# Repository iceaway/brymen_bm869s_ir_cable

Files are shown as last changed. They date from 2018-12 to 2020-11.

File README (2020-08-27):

NOTE
==============
This repo has been cloned with permission from its original author at 
https://git.e1e0.net/brymen_bm869s_ir_cable.git

The modifications I made were to make it work with an attiny84a MCU which I 
happened to have available. The schematic has been updated to reflect this 
as well.
==============

# Brymen 869s Serial cable

BOM:

  * micro controller ATTiny85
  * One infrared diode.
  * One photodiode.
  * 3 resistors (75R 4k7 2k)
  * One NPN BJT (like the 2N2222A)
  * A usb to serial adapter that can provid 5v.

I built it on a perfboard, so no pcb design is provided.

The 3D desigh fits perfectly and leaves 48 x 11 mm (more or less) of
space for the pcb. An STL file can be found at (in case you don't know
how to use FreeCAD):

https://onna.be/files/brymen_cable_attachemnt_v2.stl

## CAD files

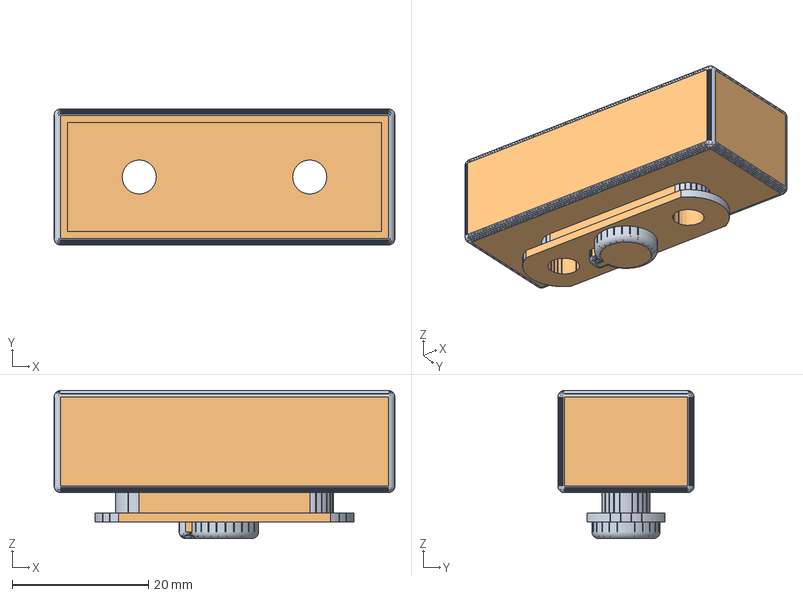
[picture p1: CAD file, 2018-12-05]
CAD/mechanical/cable_attachment.fcstd
50.0 x 20.0 x 21.7 mm
Fillet001 (Meshed)

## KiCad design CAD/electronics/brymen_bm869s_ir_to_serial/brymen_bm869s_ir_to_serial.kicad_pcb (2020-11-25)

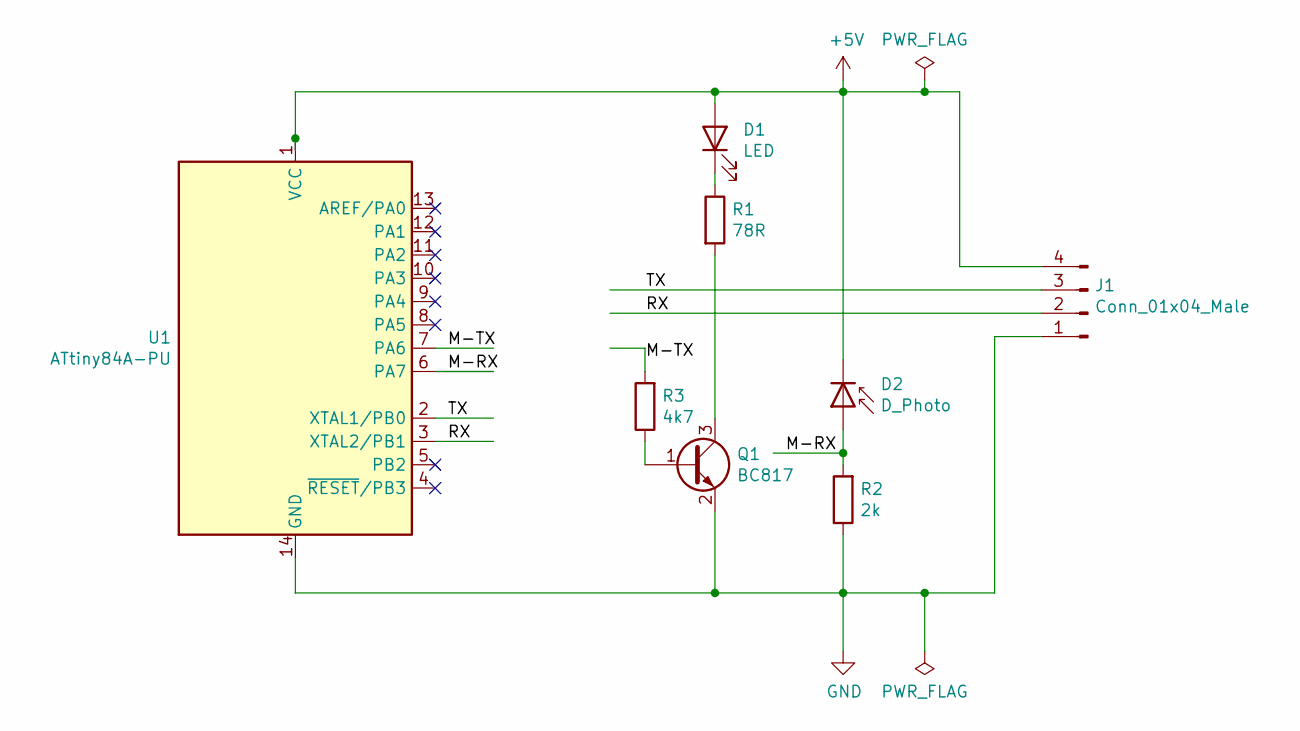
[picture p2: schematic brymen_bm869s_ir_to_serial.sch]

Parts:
D1: LED; LED_D4.0mm
D2: D_Photo; LED_D4.0mm
J1: Conn_01x04_Male; PinHeader_1x04_P2.54mm_Vertical
Q1: BC817; SOT-23
R1: 78R; R_0603_1608Metric
R2: 2k; R_0603_1608Metric
R3: 4k7; R_0603_1608Metric
U1: ATtiny84A-PU; DIP-14_W7.62mm

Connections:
+5V: D1.2 (A), D2.1 (K), J1.4, U1.1 (VCC)
/M-RX: D2.2 (A), R2.2, U1.6 (PA7)
/M-TX: R3.2, U1.7 (PA6)
/RX: J1.2, U1.3 (XTAL2/PB1)
/TX: J1.3, U1.2 (XTAL1/PB0)
GND: J1.1, Q1.2 (E), R2.1, U1.14 (GND)
unnamed: D1.1 (K), R1.1
unnamed: Q1.1 (B), R3.1
unnamed: Q1.3 (C), R1.2

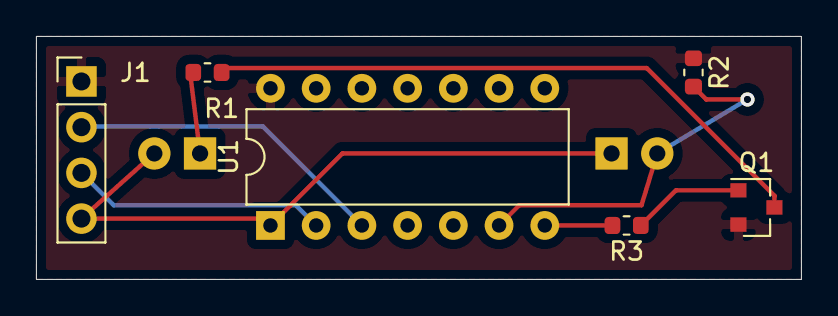
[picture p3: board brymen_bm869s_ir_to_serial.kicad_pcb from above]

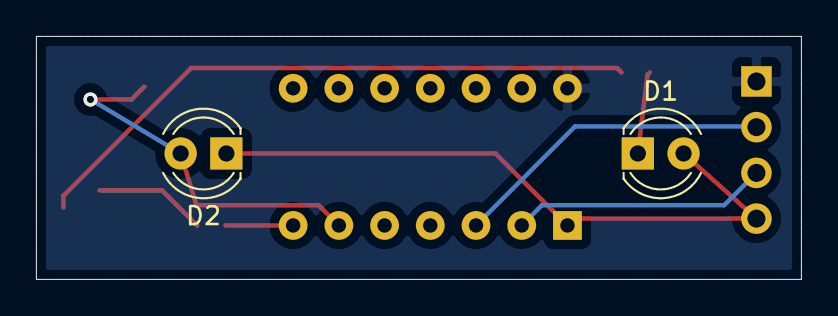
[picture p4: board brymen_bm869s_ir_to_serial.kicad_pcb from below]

Board: 2 copper layers, 42.5 x 13.5 mm, 8 parts (2 on the bottom side), 9 nets.

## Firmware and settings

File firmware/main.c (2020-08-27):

/*
 * all the relevant parts of this code have been shamelessly taken and adapted
 * from here:
 *
 * https://www.eevblog.com/forum/testgear/brymen-ir-connection-protocol-anyone-sniffed-it-yet/msg874805/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
 *
 * All credit goes to eevblog forum user 'jesuscf'. I just adapted to AVR C for
 * the ATTiny85
 */

#include <avr/io.h>
#include <util/delay.h>

#include <bm869s.h>
#include <avr305.h>

#define HIGH 1
#define LOW 0
#define IRTX PA6
#define IRRX PA7

/* Storage for the information received from the multimeter */
#define BM_PBYTES 20 /* 16 bytes with data and 4 bytes with other information */
unsigned char bm[BM_PBYTES];

void digitalWrite(int pin, int state)
{
    if (state == HIGH) {
        PORTA |= (1 << pin);
    } else {
        PORTA &= ~(1 << pin);
    }
}

unsigned char digitalRead(int pin)
{
    return (PINA & (1 << pin));
}

/* Reads a byte from the multimeter */
unsigned char getByte(void)
{
    unsigned char result, mask;

    /* bit by bit check (using shift mask)
     * clock --> check --> "unclock" */
    for (mask = 1, result = 0; mask != 0; mask <<= 1) {
        digitalWrite(IRTX, HIGH);
        _delay_us(250);

        /* checking on low instead of high, so maybe we can reuse
         * some work done on eevblog forum */
        if (digitalRead(IRRX) == LOW) result |= mask;

        digitalWrite(IRTX, LOW);
        _delay_us(250);
    }
    return result;
}

/* Reads 20 bytes from the multimeter */
int readBM689s(void)
{
    unsigned int timeout;
    unsigned char j;

    /* wait in case dmm is transmitting already */
    while (digitalRead(IRRX) == HIGH);

    /* init communication 10ms pulse */
    digitalWrite(IRTX, HIGH);
    _delay_ms(10);
    digitalWrite(IRTX, LOW);

    /* wait for dmm response */
    timeout = 0;
    while (digitalRead(IRRX) == LOW) {
        _delay_ms(1);
        timeout++;
        if (timeout > 1000) break;
    }
    /* if we did not reach timeout, get 20 bytes. */
    if (timeout <= 1000) {
        for (j = 0; j < BM_PBYTES; j++) bm[j] = getByte();
        return 1;
    }
    return 0;
}

/* Converts the digits information received into ASCII characters */
char Decode_7seg(unsigned char val)
{
    switch (val & 0xfe) {
        case LETTER_C: return'C'; break;
        case LETTER_d: return'd'; break;
        case LETTER_F: return'F'; break;
        case LETTER_i: return'i'; break;
        case LETTER_L: return'L'; break;
        case LETTER_o: return'o'; break;
        case BLANK:    return' '; break;
        case DASH:     return'-'; break;
        case NUMBER_0: return'0'; break;
        case NUMBER_1: return'1'; break;
        case NUMBER_2: return'2'; break;
        case NUMBER_3: return'3'; break;
        case NUMBER_4: return'4'; break;
        case NUMBER_5: return'5'; break;
        case NUMBER_6: return'6'; break;
        case NUMBER_7: return'7'; break;
        case NUMBER_8: return'8'; break;
        case NUMBER_9: return'9'; break;
        default:
            return'?';
            break;
    }
}

/* Sends via serial port whatever was read and decoded from the multimeter for
 * the main display */
void Send_Disp1(void)
{
    char c;

    /* + or - sign */
    if (((bm[14] & Hz_1) == 0) && ((bm[14] & DUTY) == 0)
            && ((bm[14] & OHM) == 0) && ((bm[13] & FARAD) == 0)) {
        printc(bm[1]&negative_1 ? '-' : '+');
    }

    /* main digits */
    printc(Decode_7seg(bm[2]));
    if (bm[3] & seg_p) printc('.');
    printc(Decode_7seg(bm[3]));
    if (bm[4] & seg_p) printc('.');
    printc(Decode_7seg(bm[4]));
    if (bm[5] & seg_p) printc('.');
    printc(Decode_7seg(bm[5]));
    if (bm[6] & seg_p) printc('.');
    printc(Decode_7seg(bm[6]));
    c = Decode_7seg(bm[7]);
    if (c != ' ') printc(c);

    /* Display the units of voltage or current */
    if ((bm[7] & V_1) || (bm[13] & A_1)) {
        if ((bm[14] & m_1) || (bm[14] & u_1)) {
            printc('E');
            printc('-');
            printc((bm[14] & m_1) ? '3' : '6');
        }
        printc(' ');
        if (bm[7] & V_1)
            printc('V');
        else
            printc('A');
        if (bm[0] & DC) {
            if (bm[1] & AC_1) {
                printc('R');
                printc('M');
                printc('S');
            } else {
                printc('D');
                printc('C');
            }
        } else if (bm[1] & AC_1) {
            printc('A');
            printc('C');
        }
    }

    /* Frequency */
    if (bm[14] & Hz_1) {
        if ((bm[14] & k_1) || (bm[14] & M_1)) {
            printc('E');
            printc('+');
            if (bm[14] & k_1)
                printc('3');
            else
                printc('6');
        }
        printc(' ');
        printc('H');
        printc('z');
    }

    /* Duty cycle */
    if (bm[14] & DUTY) {
        printc(' ');
        printc('D');
        printc('%');
    }

    /* dB */
    if (bm[14] & dB) {
        printc(' ');
        printc('d');
        printc('B');
        if (bm[14] & m_1) printc('m');
    }

    /* Resistance */
    if (bm[14] & OHM) {
        if ((bm[14] & k_1) || (bm[14] & M_1)) {
            printc('E');
            printc('+');
            if (bm[14] & k_1)
                printc('3');
            else
                printc('6');
        }
        printc(' ');
        printc('O');
        printc('H');
        printc('M');
    }

    /* Capacitance */
    if (bm[13] & FARAD) {
        if ((bm[13] & n) || (bm[14] & u_1) || (bm[14] & m_1)) {
            printc('E');
            printc('-');
            if (bm[13] & n)        printc('9');
            else if (bm[14] & u_1) printc('6');
            else if (bm[14] & m_1) printc('3');
        }
        printc(' ');
        printc('F');
    }
}

/* Sends via serial port whatever was read and decoded from the multimeter for
 * the second display */
void Send_Disp2(void)
{
    char c;

    c = Decode_7seg(bm[9]);

    if (c != ' ') {
        printc(bm[8]&negative_2 ? '-' : '+');
        printc(Decode_7seg(bm[9]));
        if (bm[10] & seg_p) printc('.');
        printc(Decode_7seg(bm[10]));
        if (bm[11] & seg_p) printc('.');
        printc(Decode_7seg(bm[11]));
        if (bm[12] & seg_p) printc('.');
        printc(Decode_7seg(bm[12]));

        /* Display the units of voltage or current */
        if ((bm[13] & V_2) || (bm[8] & A_2)) {
            if ((bm[8] & m_2) || (bm[8] & u_2)) {
                printc('E');
                printc('-');
                printc((bm[8] & m_2) ? '3' : '6');
            }
            printc(' ');
            if (bm[13] & V_2)
                printc('V');
            else
                printc('A');
            if (bm[8] & AC_2) {
                printc('A');
                printc('C');
            } else {
                printc('D');
                printc('C');
            }
        }

        /* Frequency */
        if (bm[13] & Hz_2) {
            if ((bm[13] & k_2) || (bm[13] & M_2)) {
                printc('E');
                printc('+');
                if (bm[13] & k_2)
                    printc('3');
                else
                    printc('6');
            }
            printc(' ');
            printc('H');
            printc('z');
        }
    }
}

int main(void)
{
    /* Pin initialization */
    DDRA |= (1 << IRTX);         /* port output */
    DDRA &= ~(1 << IRRX);        /* port input */
    PORTA &= ~(1 << IRTX);       /* set output ports to low */

    while (1) {
        readBM689s();
        Send_Disp1();
        printc(' ');
        Send_Disp2();
        printc('\r');
        printc('\n');
        _delay_ms(200);
    }

    return 0;
}

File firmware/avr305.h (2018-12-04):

#ifndef AVR305_H
#define AVR305_H

/* See LICENSE file for copyright and license details. */
#include <avr/io.h>
#include <avr/interrupt.h>

//Set tx to PB2 / rx to PB1
#define UART_Port _SFR_IO_ADDR(PORTB)
#define UART_Tx 0
#define UART_Rx 1

//Define baudrate
#define BAUD_RATE 115200

//Calculate delays
#ifdef F_CPU
#define TXDELAY (((F_CPU/BAUD_RATE)-7 +1.5)/3)
#define RXDELAY (((F_CPU/BAUD_RATE)-5 +1.5)/3)
#else
  #error CPU frequency F_CPU undefined
#endif

void printc(char ch) {
	uint8_t txdelay = TXDELAY;
	uint8_t delayCount = 0;

	__asm__ __volatile__(
		"0: cli\n\t"
		"   sbi %[uart_port]-1,%[uart_tx]\n\t"
		"   cbi %[uart_port],%[uart_tx]\n\t"
		"   in __tmp_reg__,%[uart_port]\n\t"
		"   ldi r25,3\n\t"
		"1: mov %[delayCount],%[txdelay]\n\t"
		"2: dec %[delayCount]\n\t"
		"   brne 2b\n\t"
		"   bst %[ch],0\n\t"
		"   bld __tmp_reg__,%[uart_tx]\n\t"
		"   lsr r25\n\t"
		"   ror %[ch]\n\t"
		"   out %[uart_port],__tmp_reg__\n\t"
		"   brne 1b\n\t"
		:
		  [ch] "+r" (ch),
		  [delayCount] "+r" (delayCount)
		:
		  [uart_port] "M" (UART_Port),
		  [uart_tx] "M" (UART_Tx),
		  [txdelay] "r" (txdelay)
		:
		  "r25"
	);
}

void serialPrint(const char *string) {
	while(*string) {
		printc(*string++);
	}
    sei();
}

void serialPrintln(const char *string) {
	while(*string) {
		printc(*string++);
	}
	printc('\r');
	printc('\n');
    sei();
}

char serialReadc() {
	uint8_t rxdelay = RXDELAY;
	uint8_t rxdelay15 = (RXDELAY*1.5)-2.5;
	uint8_t delayCount = 0;

	__asm__ __volatile__(
		"0: cbi %[uart_port]-1,%[uart_rx]\n\t"
		"   sbi %[uart_port],%[uart_rx]\n\t"
		"   mov %[delayCount],%[rxdelay15]\n\t"
		"   ldi %[rxdelay15],0x80\n\t"
		"1: sbic %[uart_port]-2,%[uart_rx]\n\t"
		"   rjmp 1b\n\t"
		"   cli\n\t"
		"2: subi %[delayCount], 1\n\t"
		"   brne 2b\n\t"
		"   mov %[delayCount],%[rxdelay]\n\t"
		"   sbic %[uart_port]-2,%[uart_rx]\n\t"
		"   sec\n\t"
		"   ror %[rxdelay15]\n\t"
		"   brcc 2b\n\t"
		"3: dec %[delayCount]\n\t"
		"   brne 3b\n\t"
	:
	  [rxdelay15] "+r" (rxdelay15),
	  [delayCount] "+r" (delayCount)
	:
	  [uart_port] "M" (UART_Port),
	  [uart_rx] "M" (UART_Rx),
	  [rxdelay] "r" (rxdelay)
	);
	return rxdelay15;
}

#endif

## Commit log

2018-12-03 initial version
    [cable_attachment.fcstd]
2018-12-03 refining shape to test better fit.
    [cable_attachment.fcstd]
2018-12-03 trying for better fit with dimensions from EEVblog forum
    [cable_attachment.fcstd]
2018-12-05 first working version + some comments and small fixes
    [main.c]
2018-12-05 final 3d model version
    [cable_attachment.fcstd]
2020-08-27 Modified code to be work with an attiny84a MCU
    [brymen_bm869s_ir_to_serial.sch]
2020-08-29 Added a PCB design, but it has not been verified.
    [brymen_bm869s_ir_to_serial.kicad_pcb, brymen_bm869s_ir_to_serial.sch]
2020-11-25 Wrong distance between the IR-diodes, would not fit in the enclosure.
    [brymen_bm869s_ir_to_serial.kicad_pcb]
2020-11-25 Something changed apparantly
    [brymen_bm869s_ir_to_serial.kicad_pcb]
